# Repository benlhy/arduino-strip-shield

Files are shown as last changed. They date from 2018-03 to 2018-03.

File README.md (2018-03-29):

# Arduino Strip Shield
Schematics for a LED strip driver Arduino shield. Good for up to 1A! Can be used with 12V light strips, 12V RGB strips, and 5V neopixel strips.

WARNING: If you want to use the power from the VIN pin to power your neopixel strip, you will need a step-down voltage regulator from 12V to 5V before connecting your neopixel strip because the PWR pin supplies power directly from the DC jack. Connecting a 5V power supply to the DC jack will NOT work because it needs 7-12V to feed into the Arduino.

Remember to disconnect DC power when connecting the programming header just to be safe.

Use RTClib to use the RTC, and Radiohead to use the NRF24L01

D3: Power (PWM)
D4: Neopixel
D5: Red
D6: Green
D9: Blue

# To test
* Connect 5V DC power and USB power. Board should be powered.
* Jump VIN to 5V if 5V DC supply, and cut the VIN connection. Board should be powered.

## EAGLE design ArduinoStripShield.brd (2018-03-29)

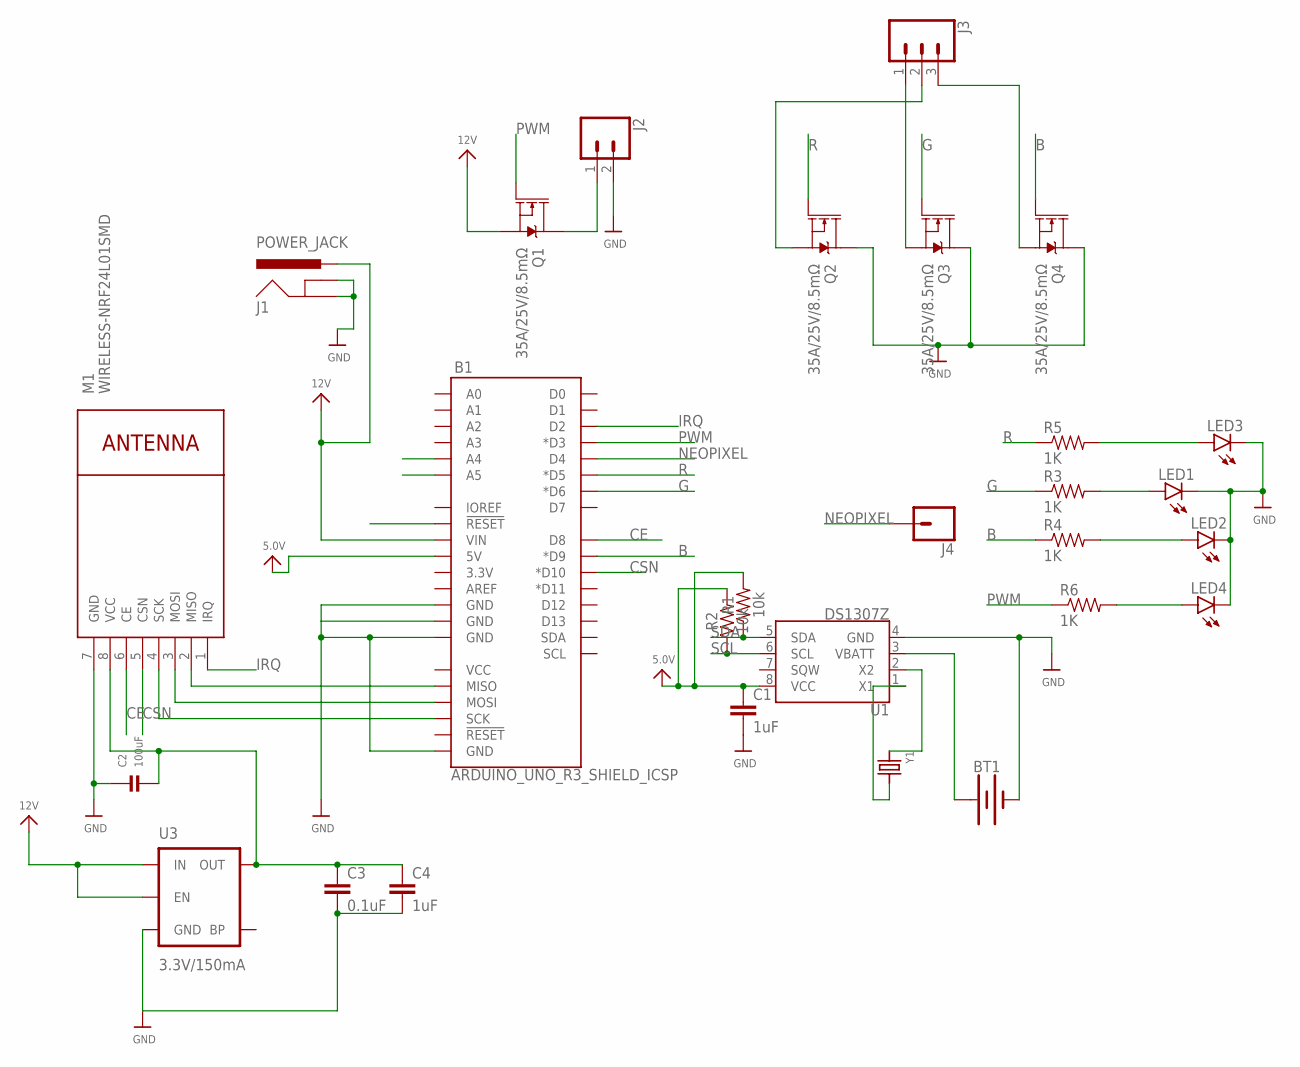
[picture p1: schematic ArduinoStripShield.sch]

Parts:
B1: ARDUINO_UNO_R3_SHIELD_ICSP; UNO_R3_SHIELD_ICSP
BT1: BATTERY-12MM_SMD; BATTCON_12MM
C1, C4: 1uF; 0805
C2: 100uF; 1206
C3: 0.1uF; 0805
J1: POWER_JACK; POWER_JACK_PTH
J2: CONN_02; 1X02
J3: CONN_03; 1X03
J4: CONN_01; 1X01
LED1, LED2, LED3, LED4: LED0603; LED-0603
M1: WIRELESS-NRF24L01SMD; WIRELESS-NRF24L01-SMD
Q1, Q2, Q3, Q4: 35A/25V/8.5mΩ; DPAK
R1, R2: 10k; 0603
R3, R4, R5, R6: 1K; 0603-RES
U1: DS1307Z; SO08-0.15
U3: 3.3V/150mA; SOT23-5
Y1: CRYSTAL8X3.8SMT; CRYSTAL_8X3.8

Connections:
5.0V: B1.5V, C1.1, R1.2, R2.2, U1.8 (VCC)
12V: B1.VIN, J1.PWR, Q1.3 (S), U3.1 (IN), U3.3 (EN)
B: B1.D9 (*D9), Q4.1 (G), R4.1
CE: B1.D8, M1.6 (CE)
CSN: B1.D10 (*D10), M1.5 (CSN)
G: B1.D6 (*D6), Q3.1 (G), R3.1
GND: B1.GND@0 (GND), B1.GND@1 (GND), B1.GND@2 (GND), B1.GND_ICSP (GND), BT1.GND (-), C1.2, C2.1, C3.2, C4.2, J1.GND, J1.GNDBREAK, J2.2, LED1.C, LED2.C, LED3.C, LED4.C, M1.7 (GND), Q2.4 (D), Q3.4 (D), Q4.4 (D), U1.4 (GND), U3.2 (GND)
IRQ: B1.D2, M1.1 (IRQ)
unnamed: J2.1, Q1.4 (D)
unnamed: B1.MISO, M1.2 (MISO)
unnamed: B1.MOSI, M1.3 (MOSI)
unnamed: J3.1, Q3.3 (S)
unnamed: J3.2, Q2.3 (S)
unnamed: J3.3, Q4.3 (S)
unnamed: BT1.PWR@1 (+), U1.3 (VBATT)
unnamed: U1.2 (X2), Y1.P$1 (1)
unnamed: U1.1 (X1), Y1.P$4 (2)
unnamed: B1.SCK, M1.4 (SCK)
unnamed: C2.2, C3.1, C4.1, M1.8 (VCC), U3.5 (OUT)
unnamed: LED2.A, R4.2
unnamed: LED4.A, R6.2
unnamed: LED3.A, R5.2
unnamed: LED1.A, R3.2
NEOPIXEL: B1.D4, J4.1
PWM: B1.D3 (*D3), Q1.1 (G), R6.1
R: B1.D5 (*D5), Q2.1 (G), R5.1
RST: B1.RES (!RESET!)
SCL: B1.A5, R2.1, U1.6 (SCL)
SDA: B1.A4, R1.1, U1.5 (SDA)

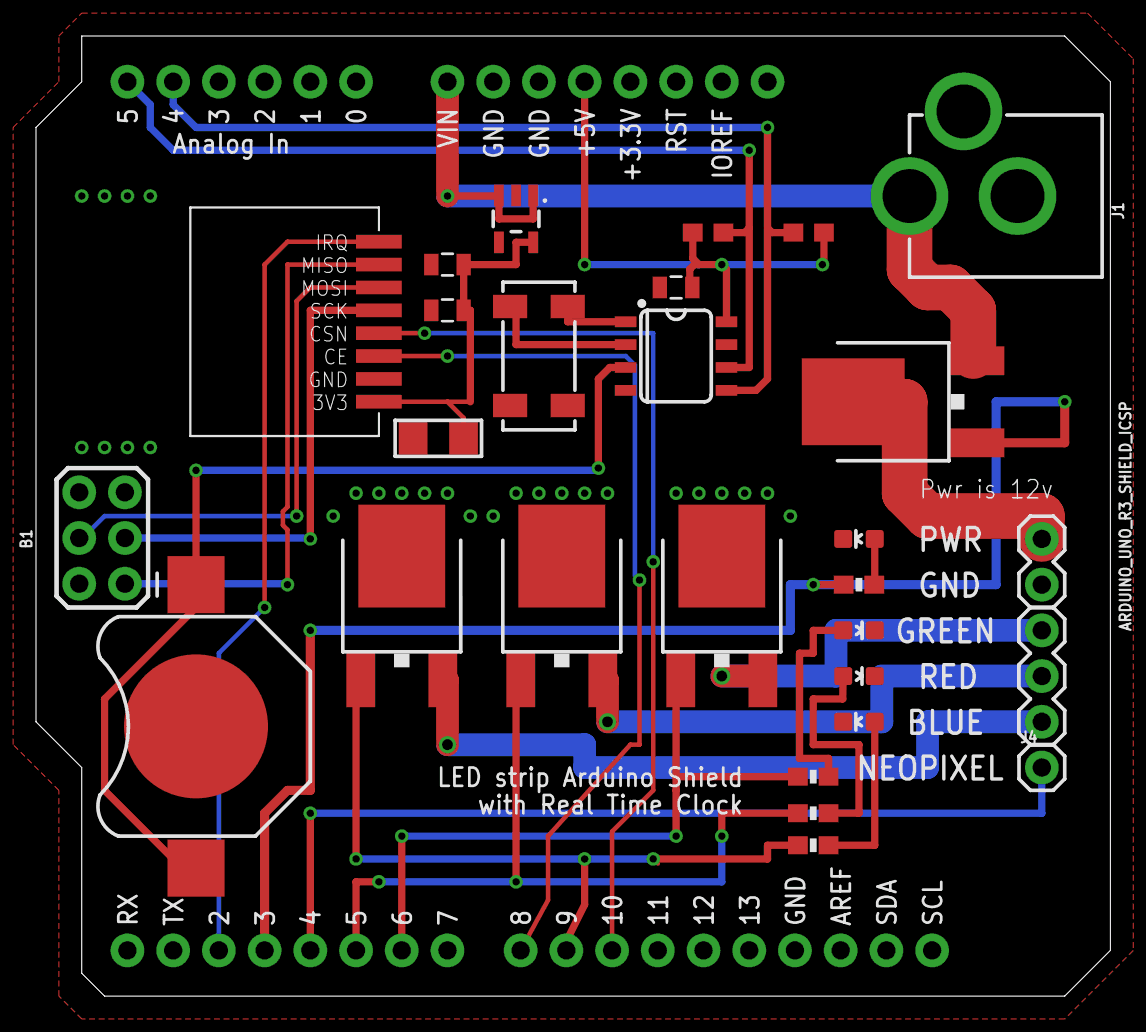
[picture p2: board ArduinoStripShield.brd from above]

Board: 2 copper layers, 59.7 x 53.3 mm, 28 parts (0 on the bottom side), 28 nets.

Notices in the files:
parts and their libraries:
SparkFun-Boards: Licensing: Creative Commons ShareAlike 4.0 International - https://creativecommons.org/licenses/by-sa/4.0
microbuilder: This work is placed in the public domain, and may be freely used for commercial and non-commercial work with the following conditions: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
